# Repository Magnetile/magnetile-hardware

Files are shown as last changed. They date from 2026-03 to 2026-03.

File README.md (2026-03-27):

<div align="center">

Magnetile

# Magnetile Hardware

**Open source modular wireless macropad system**


[]()
[]()
[]()

</div>

---

Magnetile is a modular wireless input device. A central hub connects to interchangeable input tiles - mechanical keys, rotary encoders, sliders, display keys - via magnetic pogo pin connectors. The hub presents as a single BLE HID device to the host. Everything is open source.

> **Personal project by a maker in Bavaria, Germany. Not for commercial sale.**

---

## System Overview

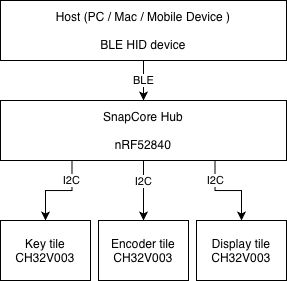
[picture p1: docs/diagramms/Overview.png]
System Overview


Tiles are hot-swappable modules. Each tile has its own small MCU communicating over I²C. The hub aggregates all input and handles the BLE stack. A single LiPo cell in the hub powers the entire system through the pogo pins.

---

## SnapCore Hub Board

The SnapCore is the first hardware in this repository — the nRF52840-based hub PCB.

### Hardware Stack

| Component | Part | Notes |
|---|---|---|
| MCU | Nordic nRF52840 (AQFN-73) | BLE 5, USB, 1MB flash, 256KB RAM |
| LDO | XC6220B331MR-G (Torex, SOT-23-5) | 3.3V, 1A, ~8µA quiescent |
| Battery charger | TP4056 | Single-cell LiPo, ~300mA charge rate |
| USB | USB-C, 5.1kΩ CC pull-downs |  |
| HF crystal | 32 MHz | nRF52840 system clock |
| RTC crystal | 32.768 kHz | Low-power RTC |
| QSPI flash | W25Q128 (16 MB) | Planned for rev 2 |
| Antenna | PCB trace (meander) | SWRA117D reference, tunable RF matching |
| Tile bus | I²C with 4.7kΩ pull-ups | Pogo pin connector |

### PCB Stackup

| Layer | Function |
|---|---|
| F.Cu | Components + signals |
| In1.Cu | Solid GND plane |
| In2.Cu | Power distribution + overflow signals |
| B.Cu | Signals |

- Copper pour excluded from antenna area

### Pinout

Magnetile

---

## Tile Architecture

Tiles are designed to be cheap and simple. The hub owns the BLE stack; tiles just report their input state over I²C when polled.

**Tile MCU target:** CH32V003 (RISC-V, I²C slave)

Each tile exposes:
- I²C slave address (configurable per tile type)
- Input state register (key states, encoder delta, slider position)
- Optional: small display framebuffer via I²C (for display tiles)

The pogo pin connector carries: `VCC`, `GND`, `SDA`, `SCL`, and an optional `INT` line for event-driven wake.

Full tile specification in [`docs/connector-pinout.md`](docs/Pinout.svg).

---

## Software

Firmware lives in the companion repository: [magnetile-firmware](https://github.com/magnetile/magnetile-firmware)

| Component | Stack |
|---|---|
| RTOS | Zephyr / Nordic NCS |
| BLE profile | HID over GATT |
| Wireless config | Web Bluetooth API (browser-based) |
| Debug | RTT (Segger J-Link / nRF9160 DK) |
| Hub–tile protocol | I²C polling, CH32V003 slave firmware |

---

## Status

| Milestone | Status |
|---|---|
| Schematic rev 1 | ✅ Complete |
| PCB layout rev 1 | ✅ Complete |
| Fab files (JLCPCB) | 🔄 In progress |
| Rev 1 bring-up | ⏳ Pending |
| Tile hardware | ⏳ Rev 2 |
| Firmware (hub) | 🔄 In progress |
| Tile firmware | ⏳ Rev 2 |
| Web config UI | ⏳ Planned |

---

## Building / Ordering

All design files are in KiCad 9. Fab outputs (Gerbers, BOM, CPL) for JLCPCB are in `snapcore/fab/`.

**Preferred suppliers:** JLCPCB (PCB + assembly), LCSC (components).

This project is designed around JLCPCB's manufacturing ecosystem. If you want to replicate the build, the Gerbers and BOM are ready to upload directly:

[**Order PCBs / PCBA from JLCPCB**](https://jlcpcb.com/?from=mnt)

For managing orders across services - PCB fabrication, assembly, 3D printing, CNC - JLCPCB offers **JLCONE**, a unified desktop platform that consolidates their full manufacturing stack (JLCPCB, JLC3DP, JLCCNC, JLCMC) into one interface. You can upload files, place orders, and track shipments across all services in one place. The desktop version includes a coupon bundle covering various services and shipping.

[**Download JLCONE**](https://jlcpcb.com/download?from=mnt)

---

## Acknowledgements

This project's prototype run is supported by **[JLCPCB](https://jlcpcb.com/?from=mnt)**. Their PCB fabrication and SMT assembly service makes iterating on dense, complex boards like the SnapCore genuinely accessible for independent open source hardware projects.

---

## License

MIT - see [`LICENSE`](LICENSE).

---

## Contributing

This is a personal project in active development. Issues and suggestions are welcome. See [`CONTRIBUTING.md`](CONTRIBUTING.md) before opening a pull request.

---

<div align="center">
<sub>Made in Bavaria · nRF52840 · KiCad · Zephyr</sub>
</div>

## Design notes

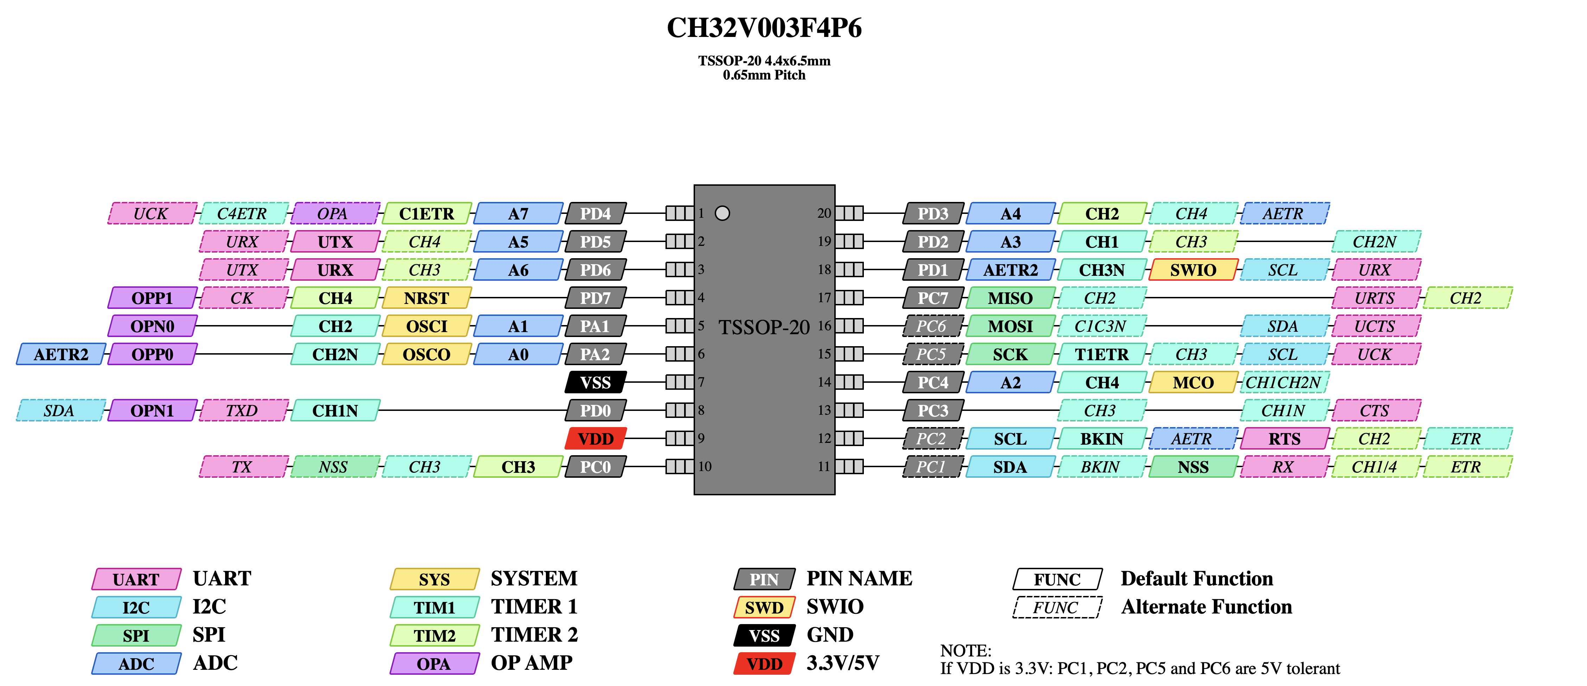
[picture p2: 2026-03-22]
Tiles/docs/CH32V003/Pinout-TSSOP-20.png

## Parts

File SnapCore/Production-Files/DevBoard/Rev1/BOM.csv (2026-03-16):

Comment | Designator | Footprint | LCSC | Quantity
0.5pF | C16 | C_0402_1005Metric | C1544 | 1
0.8pF | C15 | C_0402_1005Metric | C40459 | 1
0R | R7 | R_0603_1608Metric | C95177 | 1
100K | R6 | R_0402_1005Metric | C25741 | 1
100NF | C7 | C_0805_2012Metric | C49678 | 1
100nF | C18 | C_0603_1608Metric | C14663 | 1
100nF | C8 | C_0402_1005Metric | C1525 | 1
100pF | C19 | C_0402_1005Metric | C1546 | 1
10k | R18 | R_0402_1005Metric | C25744 | 1
10uF | C2,C24 | C_0402_1005Metric | C15525 | 2
10uH | L2 | L_0402_1005Metric | C48946156 | 1
12pF | C10,C20,C21,C9 | C_0402_1005Metric | C1547 | 4
1M_1% | R22 | R_0603_1608Metric | C22935 | 1
1k | R3,R4 | R_0603_1608Metric | C21190 | 2
1nF | C17 | C_0402_1005Metric | C1523 | 1
2.2k | R9 | R_0402_1005Metric | C25879 | 1
2.2uF | C1,C13,C22,C3 | C_0402_1005Metric | C12530 | 4
2.2uF | C11,C12 | C_0603_1608Metric | C23630 | 2
2.2uF | C23 | C_0805_2012Metric | C377773 | 1
32.768KHz | Y1 | Crystal_SMD_2016-4Pin_2.0x1.6mm | C437148 | 1
32MHz | Y2 | Crystal_SMD_2016-4Pin_2.0x1.6mm | C187794 | 1
33R | R19,R20 | R_0402_1005Metric | C25105 | 2
4.7k | R16,R17 | R_0402_1005Metric | C25900 | 2
4.7nH | L1 | L_0402_1005Metric | C13595 | 1
4k | R5 | R_0603_1608Metric | C22940 | 1
5.1k | R1,R2 | R_0402_1005Metric | C25905 | 2
500mA | F2 | Fuse_1206_3216Metric | C20798 | 1
510k_1% | R23 | R_0603_1608Metric | C23192 | 1
820pF | C14 | C_0402_1005Metric | C1523 | 1
AO3407A | Q1 | SOT-23 | C15155 | 1
CHG0 | RED1 | LED_0603_1608Metric | C2286 | 1
Green | D2 | LED_0805_2012Metric | C2297 | 1
Red | D1 | LED_0805_2012Metric | C84256 | 1
SDM20U40-7, 40V;250mA | D5 | D_SOD-523 | C139439 | 1
TP4056-42-ESOP8 | U5 | SOIC-8-1EP_3.9x4.9mm_P1.27mm_EP2.41x3.3mm_ThermalVias | C16581 | 1
TS-1187A | SW2 | SW_Push_1P1T_XKB_TS-1187A | C318884 | 1
USB_C_Receptacle_USB2.0_16P | J2 | USB_C_Receptacle_GCT_USB4105-xx-A_16P_TopMnt_Horizontal | C136423 | 1
XC6220B331MR | U2 | SOT-23-5 | C3040644 | 1
nRF52840-QIXX | U1 | Nordic_AQFN-73-1EP_7x7mm_P0.5mm | C190794 | 1
SWRA117D_2.4Ghz | AE1 | Texas_SWRA117D_2.4GHz_Right |  | 1
Conn_01x18_Pin | J3 | PinHeader_1x18_P1.27mm_Vertical |  | 1

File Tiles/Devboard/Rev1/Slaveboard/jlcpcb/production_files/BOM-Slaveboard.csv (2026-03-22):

Comment | Designator | Footprint | LCSC | Quantity
100nF | C1,C2 | C_0603_1608Metric | C14663 | 2
1N4148W | D1,D10,D11,D12,D13,D14,D15,D16,D2,D3,D4,D5,D6,D7,D8,D9 | D_SOD-123 | C81598 | 16
CH32V003FxPx | U1 | TSSOP-20_4.4x6.5mm_P0.65mm | C5187096 | 1
TS-1178A | RESET | SW_Push_1P1T_XKB_TS-1187A | C318884 | 1

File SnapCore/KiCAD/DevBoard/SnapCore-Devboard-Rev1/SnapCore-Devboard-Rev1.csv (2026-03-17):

Reference | Qty | Value | DNP | Exclude from BOM | Exclude from Board | Footprint | Datasheet
AE1 | 1 | P/N 2450AT18A100E-AEC |  |  |  | RF_Antenna:Johanson_2450AT18x100 | ~
BAT_CONN2 | 1 | Battery JST 3.7V |  |  |  | Connector_JST:JST_EH_B2B-EH-A_1x02_P2.50mm_Vertical | ~
C1,C3,C11,C12,C13,C22,C23 | 7 | 2.2uF |  |  |  | Capacitor_SMD:C_0805_2012Metric | ~
C2 | 1 | 10uF |  |  |  | Capacitor_SMD:C_0603_1608Metric | ~
C7 | 1 | 100NF |  |  |  | Capacitor_SMD:C_0805_2012Metric | ~
C8,C18 | 2 | 100nF |  |  |  | Capacitor_SMD:C_0805_2012Metric | ~
C9,C10 | 2 | 10pF |  |  |  | Capacitor_SMD:C_0805_2012Metric | ~
C14 | 1 | 820pF |  |  |  | Capacitor_SMD:C_0805_2012Metric | ~
C15 | 1 | 0.8pF |  |  |  | Capacitor_SMD:C_0805_2012Metric | ~
C16 | 1 | 0.5pF |  |  |  | Capacitor_SMD:C_0805_2012Metric | ~
C17 | 1 | 1nF |  |  |  | Capacitor_SMD:C_0805_2012Metric | ~
C19 | 1 | 100pF |  |  |  | Capacitor_SMD:C_0805_2012Metric | ~
C20,C21 | 2 | 15pF |  |  |  | Capacitor_SMD:C_0805_2012Metric | ~
C24 | 1 | 10uF |  |  |  | Capacitor_SMD:C_0805_2012Metric | ~
D1 | 1 | Red |  |  |  | LED_SMD:LED_0201_0603Metric | ~
D2 | 1 | Green |  |  |  | LED_SMD:LED_0201_0603Metric | ~
D5 | 1 | SDM20U40-7, 40V;250mA |  |  |  | Diode_SMD:D_SOD-523 | ~
F2 | 1 | 500mA |  |  |  | Fuse:Fuse_1206_3216Metric | ~
J2 | 1 | USB_C_Receptacle_USB2.0_16P |  |  |  | Connector_USB:USB_C_Receptacle_GCT_USB4105-xx-A_16P_TopMnt_Horizontal | https://www.usb.org/sites/default/files/documents/usb_type-c.zip
J_3V3 | 1 | 3V3 |  |  |  | Connector_PinHeader_1.00mm:PinHeader_1x01_P1.00mm_Vertical | ~
J_AIN1 | 1 | AIN1 |  |  |  | Connector_PinHeader_1.00mm:PinHeader_1x01_P1.00mm_Vertical | ~
J_GND1,J_GND2 | 2 | GND |  |  |  | Connector_PinHeader_1.00mm:PinHeader_1x01_P1.00mm_Vertical | ~
J_I2C_SCL1 | 1 | I2C_SCL |  |  |  | Connector_PinHeader_1.00mm:PinHeader_1x01_P1.00mm_Vertical | ~
J_I2C_SDA1 | 1 | I2C_SDA |  |  |  | Connector_PinHeader_1.00mm:PinHeader_1x01_P1.00mm_Vertical | ~
J_NFC1 | 1 | NFC1 |  |  |  | Connector_PinHeader_1.00mm:PinHeader_1x01_P1.00mm_Vertical | ~
J_NFC2 | 1 | NFC2 |  |  |  | Connector_PinHeader_1.00mm:PinHeader_1x01_P1.00mm_Vertical | ~
J_PDM_CLK1 | 1 | PDM_CLK |  |  |  | Connector_PinHeader_1.00mm:PinHeader_1x01_P1.00mm_Vertical | ~
J_PDM_DATA1 | 1 | PDM_DATA |  |  |  | Connector_PinHeader_1.00mm:PinHeader_1x01_P1.00mm_Vertical | ~
J_SWDCLK1 | 1 | SWDCLK |  |  |  | Connector_PinHeader_1.00mm:PinHeader_1x01_P1.00mm_Vertical | ~
J_SWDIO1 | 1 | SWDIO |  |  |  | Connector_PinHeader_1.00mm:PinHeader_1x01_P1.00mm_Vertical | ~
J_VBUS1 | 1 | VBUS |  |  |  | Connector_PinHeader_1.00mm:PinHeader_1x01_P1.00mm_Vertical | ~
L1 | 1 | 4.7nH |  |  |  | Inductor_SMD:L_0402_1005Metric | ~
L2 | 1 | 10uH |  |  |  | Inductor_SMD:L_0402_1005Metric | ~
Q1 | 1 | LP0404N3T5G |  |  |  | Package_TO_SOT_SMD:SOT-883 | ~
R1,R2 | 2 | 5.1k |  |  |  | Resistor_SMD:R_0402_1005Metric | ~
R3,R4 | 2 | 1k |  |  |  | Resistor_SMD:R_0603_1608Metric | ~
R5 | 1 | 4k |  |  |  | Resistor_SMD:R_0603_1608Metric | ~
R6 | 1 | 100K |  |  |  | Resistor_SMD:R_0402_1005Metric | ~
R9 | 1 | 2.2k |  |  |  | Resistor_SMD:R_0201_0603Metric | ~
R16,R17 | 2 | 4.7k |  |  |  | Resistor_SMD:R_0402_1005Metric | ~
R18 | 1 | 10k |  |  |  | Resistor_SMD:R_0201_0603Metric | ~
R19,R20 | 2 | 33R |  |  |  | Resistor_SMD:R_0201_0603Metric | ~
R22 | 1 | 1M_1% |  |  |  | Resistor_SMD:R_0402_1005Metric | ~
R23 | 1 | 510k_1% |  |  |  | Resistor_SMD:R_0402_1005Metric | ~
RED1 | 1 | CHG0 |  |  |  | LED_SMD:LED_0201_0603Metric | ~
SW2 | 1 | RESET PTS125 |  |  |  | Button_Switch_SMD:SW_Push_1P1T_NO_CK_KSC9xxJ | ~
U1 | 1 | nRF52840-QIXX |  |  |  | Package_DFN_QFN:Nordic_AQFN-73-1EP_7x7mm_P0.5mm | https://docs-be.nordicsemi.com/bundle/ps_nrf52840/attach/nRF52840_PS_v1.11.pdf?_LANG=enus
U2 | 1 | XC6220B331MR |  |  |  | Package_TO_SOT_SMD:SOT-23-5 | https://www.torexsemi.com/file/xc6220/XC6220.pdf
U5 | 1 | TP4056-42-ESOP8 |  |  |  | Package_SO:SOIC-8-1EP_3.9x4.9mm_P1.27mm_EP2.41x3.3mm_ThermalVias | https://www.lcsc.com/datasheet/lcsc_datasheet_2410121619_TOPPOWER-Nanjing-Extension-Microelectronics-TP4056-42-ESOP8_C16581.pdf
Y1 | 1 | 32.768KHz |  |  |  | Crystal:Crystal_SMD_2016-4Pin_2.0x1.6mm | ~
Y2 | 1 | 32MHz |  |  |  | Crystal:Crystal_SMD_2016-4Pin_2.0x1.6mm | ~

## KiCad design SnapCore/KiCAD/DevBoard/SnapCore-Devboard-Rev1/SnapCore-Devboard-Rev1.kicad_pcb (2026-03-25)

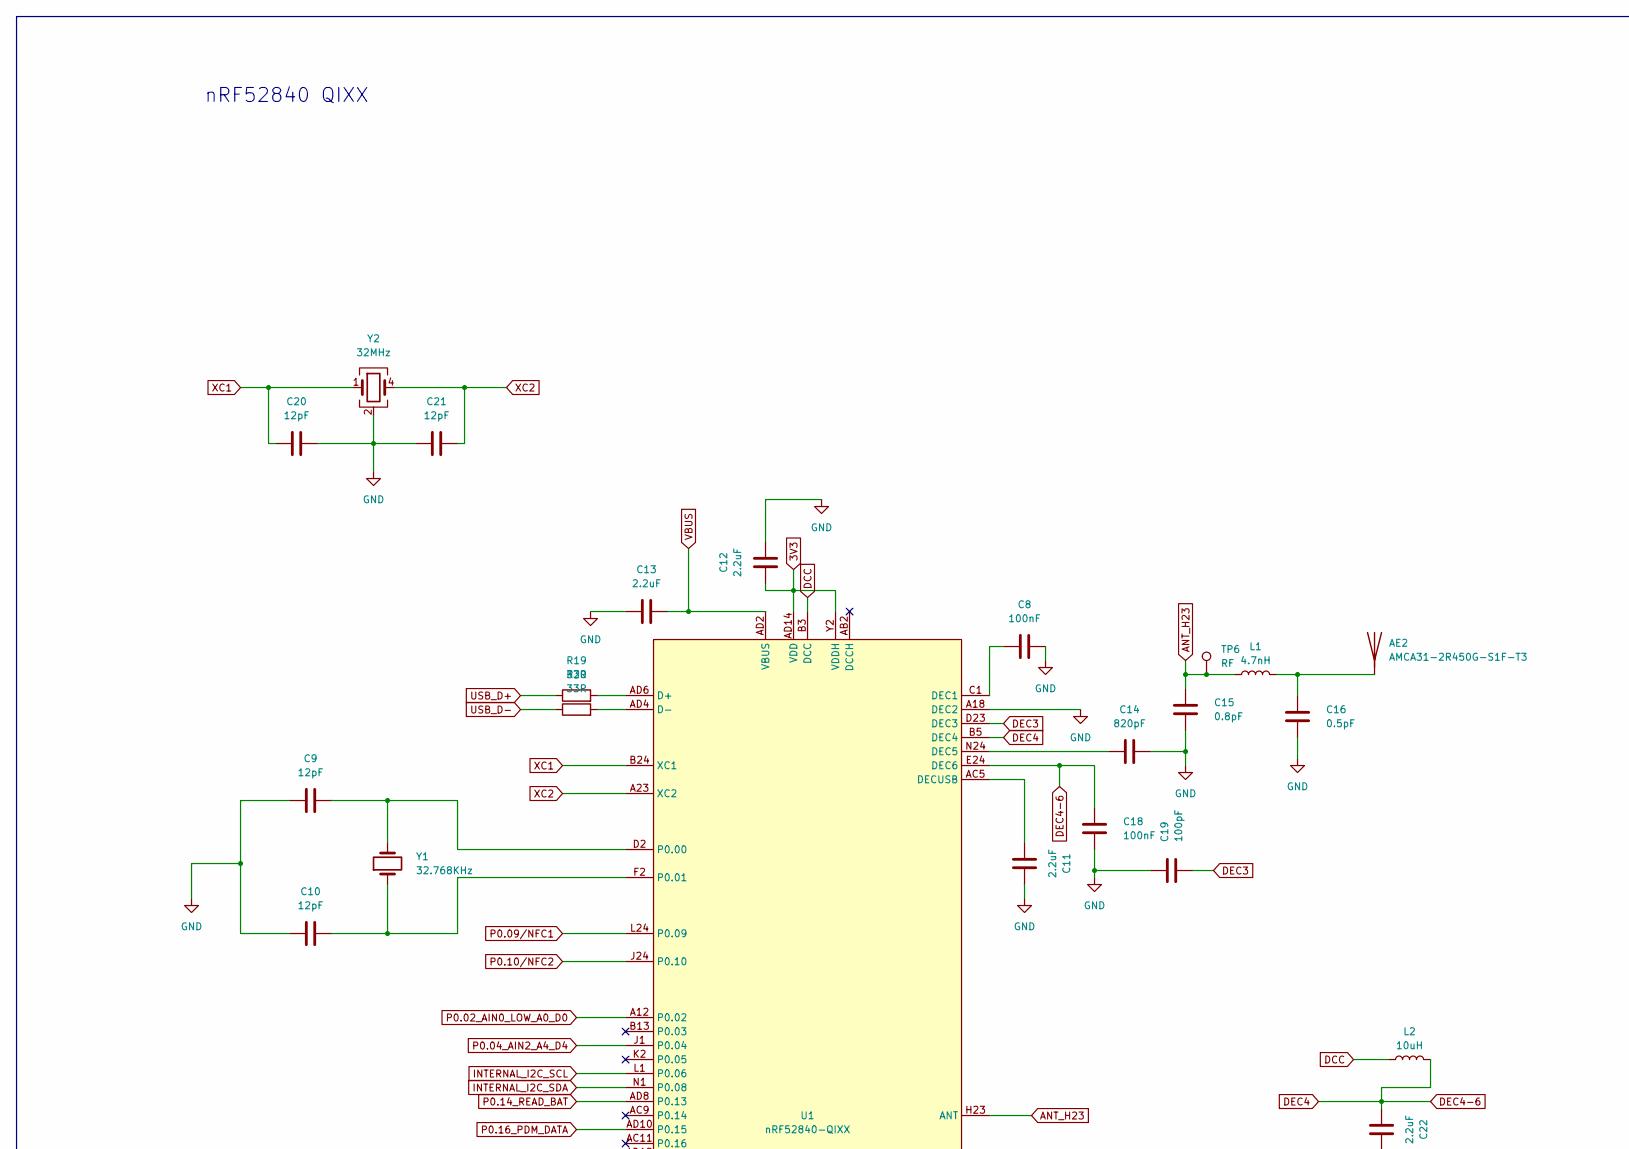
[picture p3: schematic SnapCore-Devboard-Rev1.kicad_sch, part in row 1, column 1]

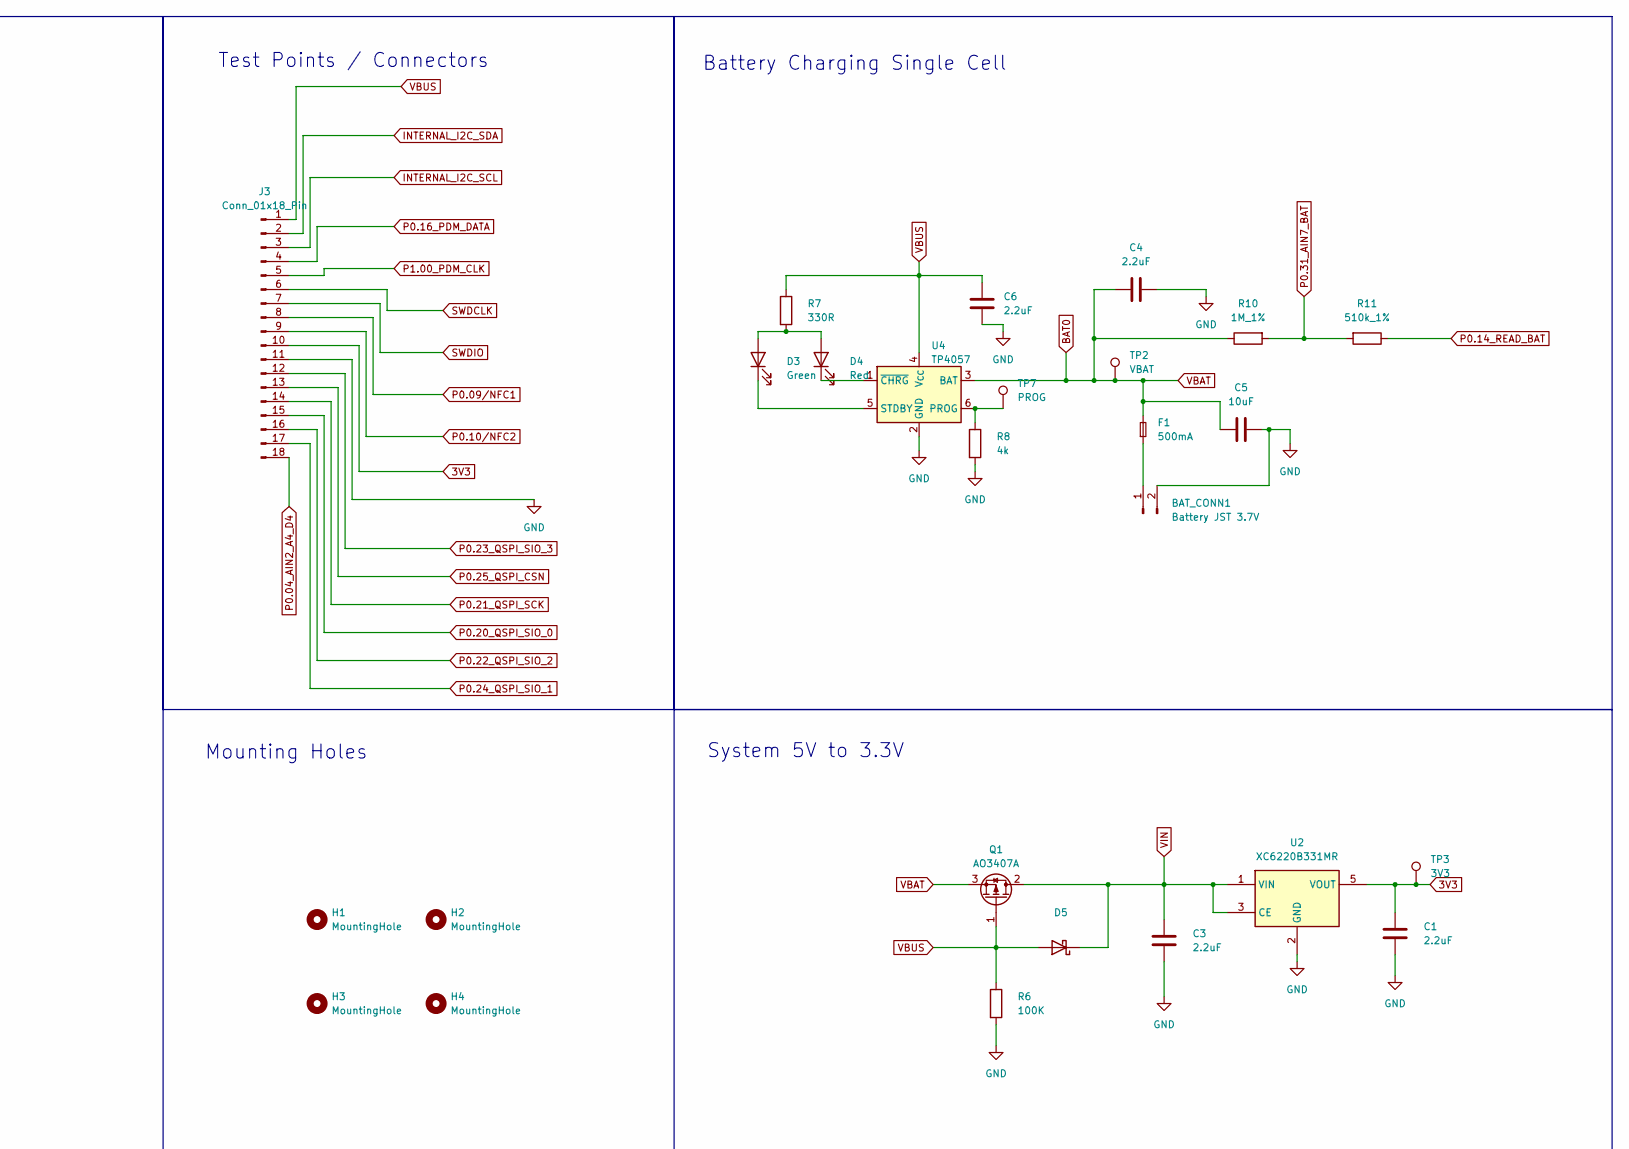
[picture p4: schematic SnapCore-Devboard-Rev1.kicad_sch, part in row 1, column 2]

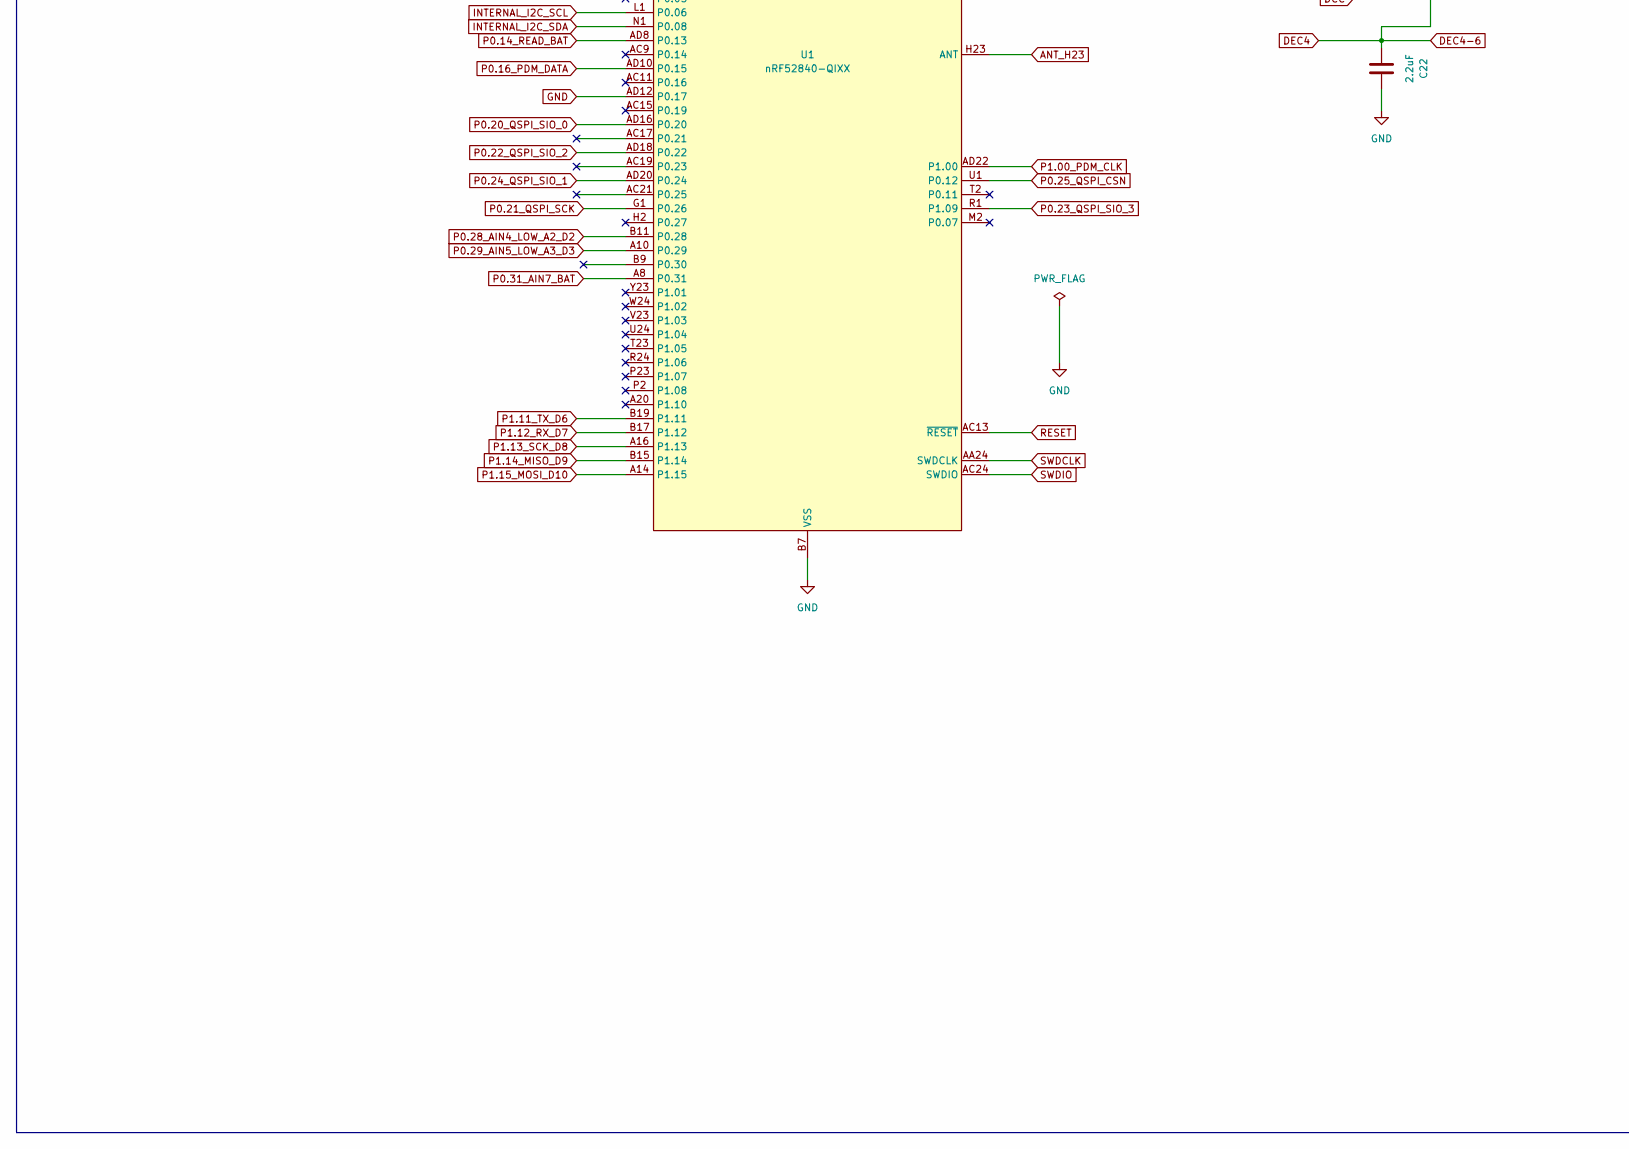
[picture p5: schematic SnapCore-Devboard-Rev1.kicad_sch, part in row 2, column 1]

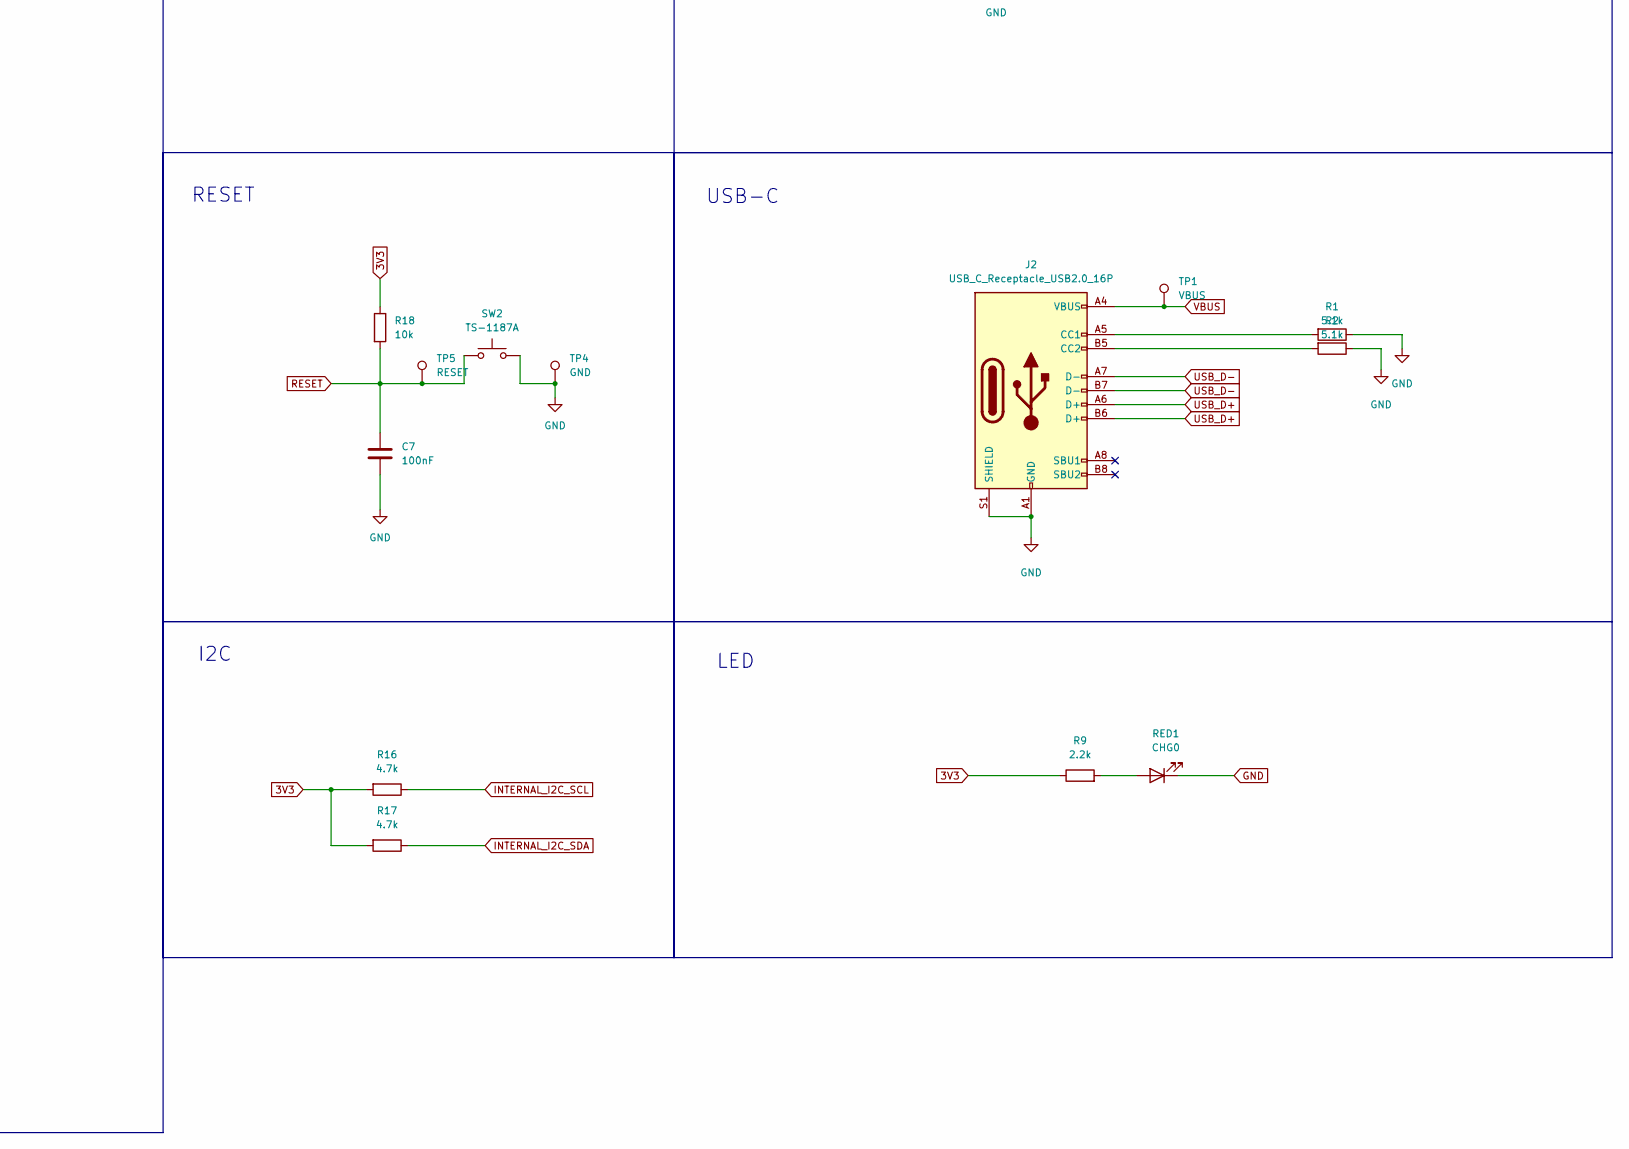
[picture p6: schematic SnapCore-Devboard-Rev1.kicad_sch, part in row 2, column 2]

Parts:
AE2: AMCA31-2R450G-S1F-T3; XDCR_AMCA31-2R450G-S1F-T3
BAT_CONN1: Battery JST 3.7V; JST_EH_B2B-EH-A_1x02_P2.50mm_Vertical
C1, C3, C13, C22: 2.2uF; C_0402_1005Metric
C4: 2.2uF; C_0805_2012Metric
C5: 10uF; C_0402_1005Metric
C6, C11, C12: 2.2uF; C_0603_1608Metric
C7: 100nF; C_0805_2012Metric
C8: 100nF; C_0402_1005Metric
C9, C10, C20, C21: 12pF; C_0402_1005Metric
C14: 820pF; C_0402_1005Metric
C15: 0.8pF; C_0402_1005Metric
C16: 0.5pF; C_0402_1005Metric
C18: 100nF; C_0603_1608Metric
C19: 100pF; C_0402_1005Metric
D3: Green; LED_0805_2012Metric
D4: Red; LED_0805_2012Metric
D5: SDM20U40-7, 40V;250mA; D_SOD-523
F1: 500mA; Fuse_1206_3216Metric
H1, H2, H3, H4: MountingHole; MountingHole_2.2mm_M2_ISO7380_Pad
J2: USB_C_Receptacle_USB2.0_16P; USB_C_Receptacle_GCT_USB4105-xx-A_16P_TopMnt_Horizontal
J3: Conn_01x18_Pin; PinHeader_1x18_P1.27mm_Vertical
L1: 4.7nH; L_0402_1005Metric
L2: 10uH; L_0402_1005Metric
Q1: AO3407A; SOT-23
R1, R2: 5.1k; R_0402_1005Metric
R6: 100K; R_0402_1005Metric
R7: 330R; R_0603_1608Metric
R8: 4k; R_0603_1608Metric
R9: 2.2k; R_0402_1005Metric
R10: 1M_1%; R_0603_1608Metric
R11: 510k_1%; R_0603_1608Metric
R16, R17: 4.7k; R_0402_1005Metric
R18: 10k; R_0402_1005Metric
R19, R20: 33R; R_0402_1005Metric
RED1: CHG0; LED_0603_1608Metric
SW2: TS-1187A; SW_Push_1P1T_XKB_TS-1187A
TP1: VBUS; TestPoint_Pad_D2.0mm
TP2: VBAT; TestPoint_Pad_D2.0mm
TP3: 3V3; TestPoint_Pad_D2.0mm
TP4: GND; TestPoint_Pad_D2.0mm
TP5: RESET; TestPoint_Pad_D2.0mm
TP6: RF; TestPoint_Pad_D2.0mm
TP7: PROG; TestPoint_Pad_D2.0mm
U1: nRF52840-QIXX; Nordic_AQFN-73-1EP_7x7mm_P0.5mm
U2: XC6220B331MR; SOT-23-5
U4: TP4057; TSOT-23-6
Y1: 32.768KHz; Crystal_SMD_3215-2Pin_3.2x1.5mm
Y2: 32MHz; Crystal_SMD_2016-4Pin_2.0x1.6mm

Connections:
3V3: C1.1, C12.2, J3.10, R9.1, R16.2, R17.2, R18.1, TP3.1, U1.A22 (VDD), U1.AD14 (VDD), U1.AD23 (VDD), U1.B1 (VDD), U1.W1 (VDD), U1.Y2 (VDDH), U2.5 (VOUT)
ANT_H23: C15.1, L1.1, TP6.1, U1.H23 (ANT)
BAT0: C4.1, C5.1, F1.2, Q1.3 (S), R10.1, TP2.1, U4.3 (BAT)
DCC: L2.1, U1.B3 (DCC)
DEC3: C19.2, U1.D23 (DEC3)
DEC4: C18.1, C22.2, L2.2, U1.B5 (DEC4), U1.E24 (DEC6)
GND: BAT_CONN1.2, C1.2, C3.2, C4.2, C5.2, C6.1, C7.1, C8.1, C9.2, C10.2, C11.1, C12.1, C13.1, C14.1, C15.2, C16.2, C18.2, C19.1, C20.1, C21.1, C22.1, J2.A1 (GND), J2.A12 (GND), J2.B1 (GND), J2.B12 (GND), J2.S1 (SHIELD), J3.11, R1.1, R2.1, R6.2, R8.2, RED1.1 (K), SW2.2, TP4.1, U1.A18 (DEC2), U1.AD12 (P0.17), U1.B7 (VSS), U1.EP (VSS), U1.F23 (VSS_PA), U2.2 (GND), U4.2 (GND), Y2.2 (G), Y2.3 (G); also elsewhere on the board
INTERNAL_I2C_SCL: J3.3, R16.1, U1.L1 (P0.06)
INTERNAL_I2C_SDA: J3.2, R17.1, U1.N1 (P0.08)
unnamed: AE2.1 (A), C16.1, L1.2
unnamed 10: BAT_CONN1.1, F1.1; also elsewhere on the board
unnamed: D3.2 (A), D4.2 (A), R7.2
unnamed: D3.1 (K), U4.5 (STDBY)
unnamed: D4.1 (K), U4.1 (~CHRG)
unnamed: J2.A5 (CC1), R1.2
unnamed: J2.B5 (CC2), R2.2
unnamed: R9.2, RED1.2 (A)
unnamed: R19.2, U1.AD6 (D+)
unnamed: R20.2, U1.AD4 (D-)
unnamed: C8.2, U1.C1 (DEC1)
unnamed: C14.2, U1.N24 (DEC5)
unnamed: C11.2, U1.AC5 (DECUSB)
unnamed: C9.1, U1.D2 (P0.00), Y1.2
unnamed: C10.1, U1.F2 (P0.01), Y1.1
unnamed: R8.1, TP7.1, U4.6 (PROG)
P0.02_AIN0_LOW_A0_D0: U1.A12 (P0.02)
P0.04_AIN2_A4_D4: J3.18, U1.J1 (P0.04)
P0.09/NFC1: J3.8, U1.L24 (P0.09)
P0.10/NFC2: J3.9, U1.J24 (P0.10)
P0.14_READ_BAT: R11.1, U1.AD8 (P0.13)
P0.16_PDM_DATA: J3.4, U1.AD10 (P0.15)
P0.20_QSPI_SIO_0: J3.15, U1.AD16 (P0.20)
P0.21_QSPI_SCK: J3.14, U1.G1 (P0.26)
P0.22_QSPI_SIO_2: J3.16, U1.AD18 (P0.22)
P0.23_QSPI_SIO_3: J3.12, U1.R1 (P1.09)
P0.24_QSPI_SIO_1: J3.17, U1.AD20 (P0.24)
P0.25_QSPI_CSN: J3.13, U1.U1 (P0.12)
P0.28_AIN4_LOW_A2_D2: U1.B11 (P0.28)
P0.29_AIN5_LOW_A3_D3: U1.A10 (P0.29)
P0.31_AIN7_BAT: R10.2, R11.2, U1.A8 (P0.31)
P1.00_PDM_CLK: J3.5, U1.AD22 (P1.00)
P1.11_TX_D6: U1.B19 (P1.11)
P1.12_RX_D7: U1.B17 (P1.12)
P1.13_SCK_D8: U1.A16 (P1.13)
P1.14_MISO_D9: U1.B15 (P1.14)
P1.15_MOSI_D10: U1.A14 (P1.15)
RESET: C7.2, R18.2, SW2.1, TP5.1, U1.AC13 (~RESET)
SWDCLK: J3.6, U1.AA24 (SWDCLK)
SWDIO: J3.7, U1.AC24 (SWDIO)
USB_D+: J2.A6 (D+), J2.B6 (D+), R19.1
USB_D-: J2.A7 (D-), J2.B7 (D-), R20.1
VBUS: C6.2, C13.2, D5.2 (A), J2.A4 (VBUS), J2.A9 (VBUS), J2.B4 (VBUS), J2.B9 (VBUS), J3.1, Q1.1 (G), R6.1, R7.1, TP1.1, U1.AD2 (VBUS), U4.4 (V_{CC})
VIN: C3.1, D5.1 (K), Q1.2 (D), U2.1 (VIN), U2.3 (CE)
XC1: C20.2, U1.B24 (XC1), Y2.1
XC2: C21.2, U1.A23 (XC2), Y2.4

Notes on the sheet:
USB-C
Test Points / Connectors
LED
Mounting Holes
RESET
I2C
Battery Charging Single Cell
System 5V to 3.3V
nRF52840 QIXX

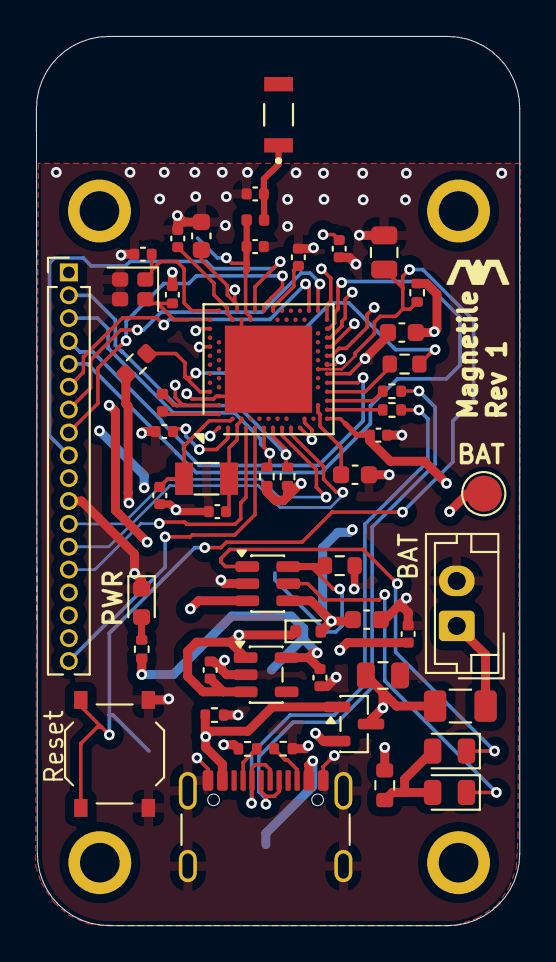
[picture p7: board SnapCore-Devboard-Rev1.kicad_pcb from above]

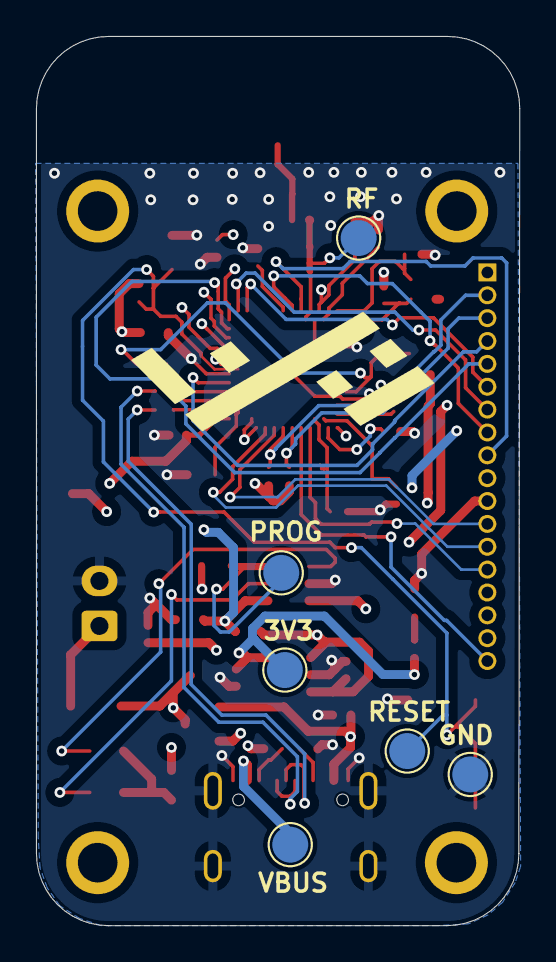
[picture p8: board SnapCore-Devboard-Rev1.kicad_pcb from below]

Board: 4 copper layers, 26.8 x 49.4 mm, 62 parts (6 on the bottom side), 47 nets.

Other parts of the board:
BAT: Battery JST 3.7V; JST_EH_B2B-EH-A_1x02_P2.50mm_Vertical

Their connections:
GND: BAT.2; also elsewhere on the board
unnamed 10: BAT.1; also elsewhere on the board

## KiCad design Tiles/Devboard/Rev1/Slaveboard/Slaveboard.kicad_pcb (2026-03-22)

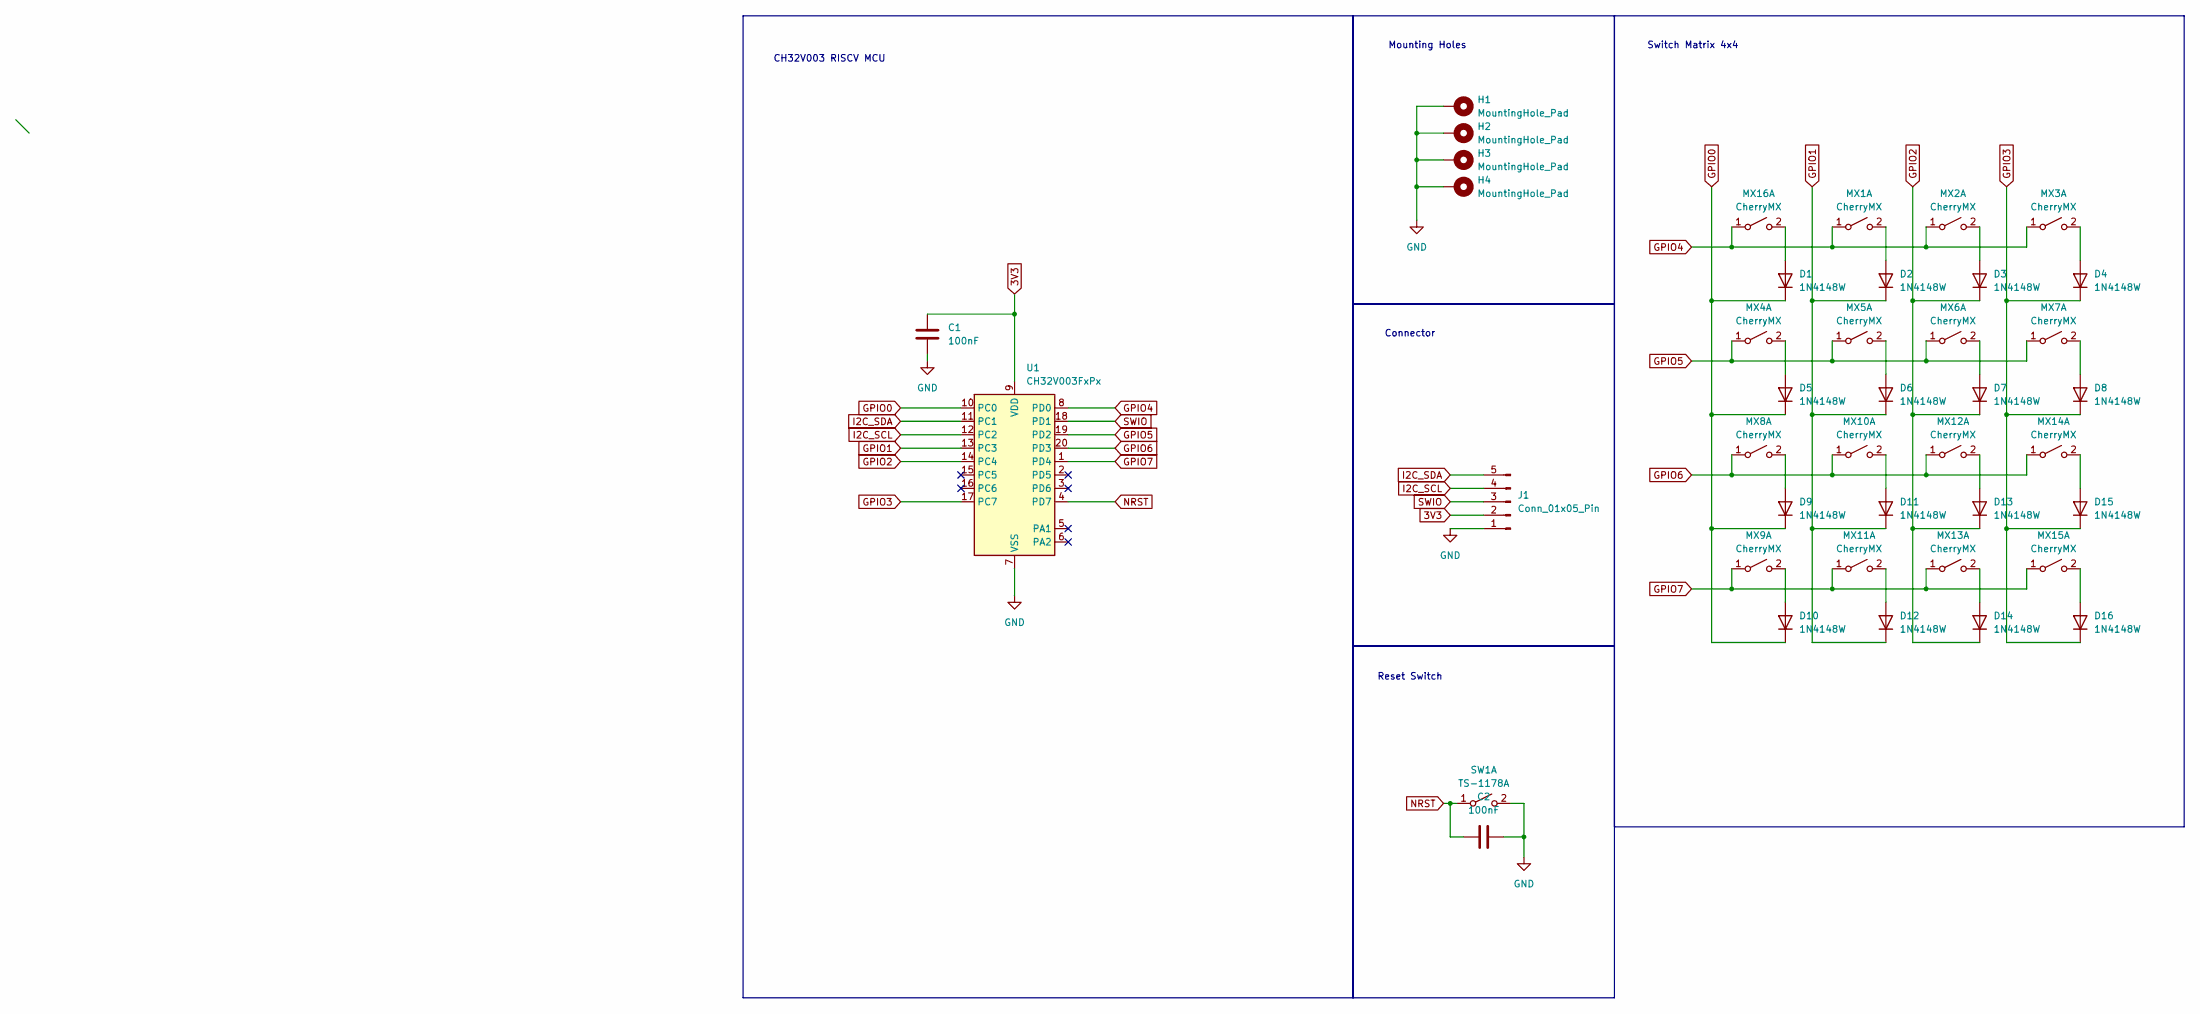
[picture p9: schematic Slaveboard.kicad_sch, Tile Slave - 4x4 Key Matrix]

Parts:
C1, C2: 100nF; C_0603_1608Metric
D1, D2, D3, D4, D5, D6, D7, D8, D9, D10, D11, D12, D13, D14, D15, D16: 1N4148W; D_SOD-123
H1, H2, H3, H4: MountingHole_Pad; MountingHole_2.2mm_M2_DIN965_Pad
J1: Conn_01x05_Pin; PinHeader_1x05_P1.27mm_Vertical
MX1, MX2, MX3, MX4, MX5, MX6, MX7, MX8, MX9, MX10, MX11, MX12, MX13, MX14, MX15, MX16: CherryMX; SW_Cherry_MX_1.00u_PCB
SW1: TS-1178A; SW_Push_1P1T_XKB_TS-1187A
U1: CH32V003FxPx; TSSOP-20_4.4x6.5mm_P0.65mm

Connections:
3V3: C1.1, J1.2, U1.9 (VDD)
GND: C1.2, C2.2, H1.1, H2.1, H3.1, H4.1, J1.1, SW1.2 (B), U1.7 (VSS); also elsewhere on the board
GPIO0: D1.1 (K), D5.1 (K), D9.1 (K), D10.1 (K), U1.10 (PC0)
GPIO1: D2.1 (K), D6.1 (K), D11.1 (K), D12.1 (K), U1.13 (PC3)
GPIO2: D3.1 (K), D7.1 (K), D13.1 (K), D14.1 (K), U1.14 (PC4)
GPIO3: D4.1 (K), D8.1 (K), D15.1 (K), D16.1 (K), U1.17 (PC7)
GPIO4: MX1.1 (A), MX2.1 (A), MX3.1 (A), MX16.1 (A), U1.8 (PD0)
GPIO5: MX4.1 (A), MX5.1 (A), MX6.1 (A), MX7.1 (A), U1.19 (PD2)
GPIO6: MX8.1 (A), MX10.1 (A), MX12.1 (A), MX14.1 (A), U1.20 (PD3)
GPIO7: MX9.1 (A), MX11.1 (A), MX13.1 (A), MX15.1 (A), U1.1 (PD4)
I2C_SCL: J1.4, U1.12 (PC2)
I2C_SDA: J1.5, U1.11 (PC1)
NRST: C2.1, SW1.1 (A), U1.4 (PD7); also elsewhere on the board
unnamed: D1.2 (A), MX16.2 (B)
unnamed: D2.2 (A), MX1.2 (B)
unnamed: D3.2 (A), MX2.2 (B)
unnamed: D4.2 (A), MX3.2 (B)
unnamed: D5.2 (A), MX4.2 (B)
unnamed: D6.2 (A), MX5.2 (B)
unnamed: D7.2 (A), MX6.2 (B)
unnamed: D8.2 (A), MX7.2 (B)
unnamed: D9.2 (A), MX8.2 (B)
unnamed: D10.2 (A), MX9.2 (B)
unnamed: D11.2 (A), MX10.2 (B)
unnamed: D12.2 (A), MX11.2 (B)
unnamed: D13.2 (A), MX12.2 (B)
unnamed: D14.2 (A), MX13.2 (B)
unnamed: D15.2 (A), MX14.2 (B)
unnamed: D16.2 (A), MX15.2 (B)
SWIO: J1.3, U1.18 (PD1)

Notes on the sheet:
Reset Switch
CH32V003 RISCV MCU
Mounting Holes
Connector
Switch Matrix 4x4

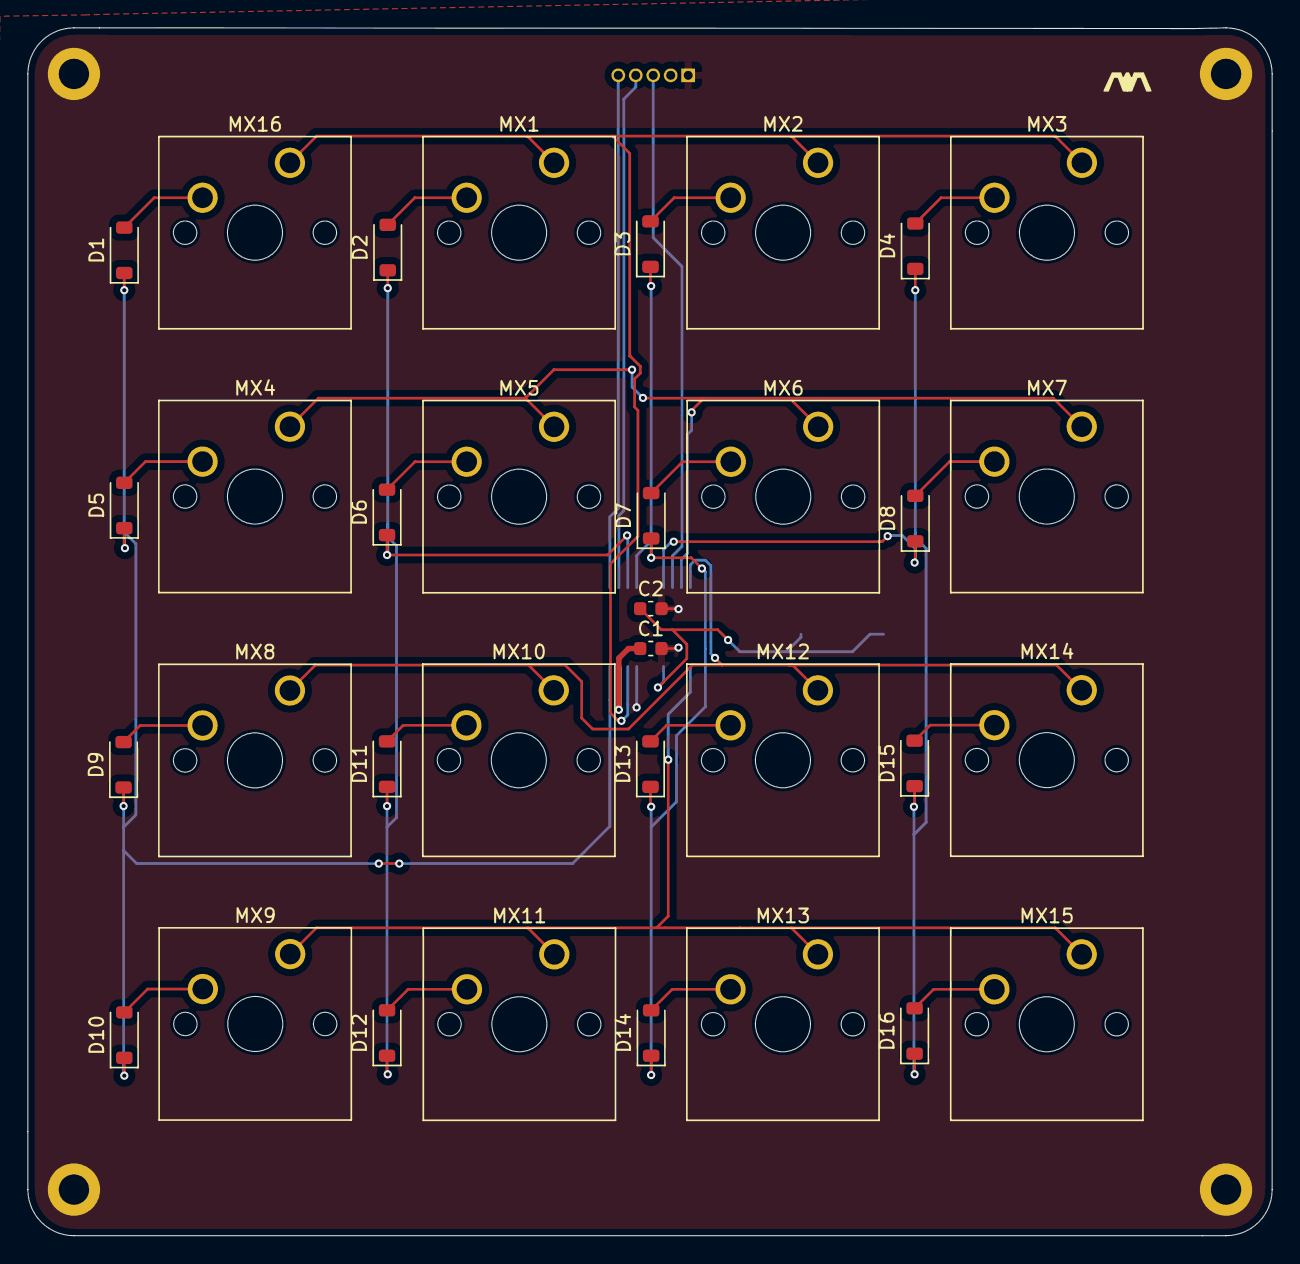
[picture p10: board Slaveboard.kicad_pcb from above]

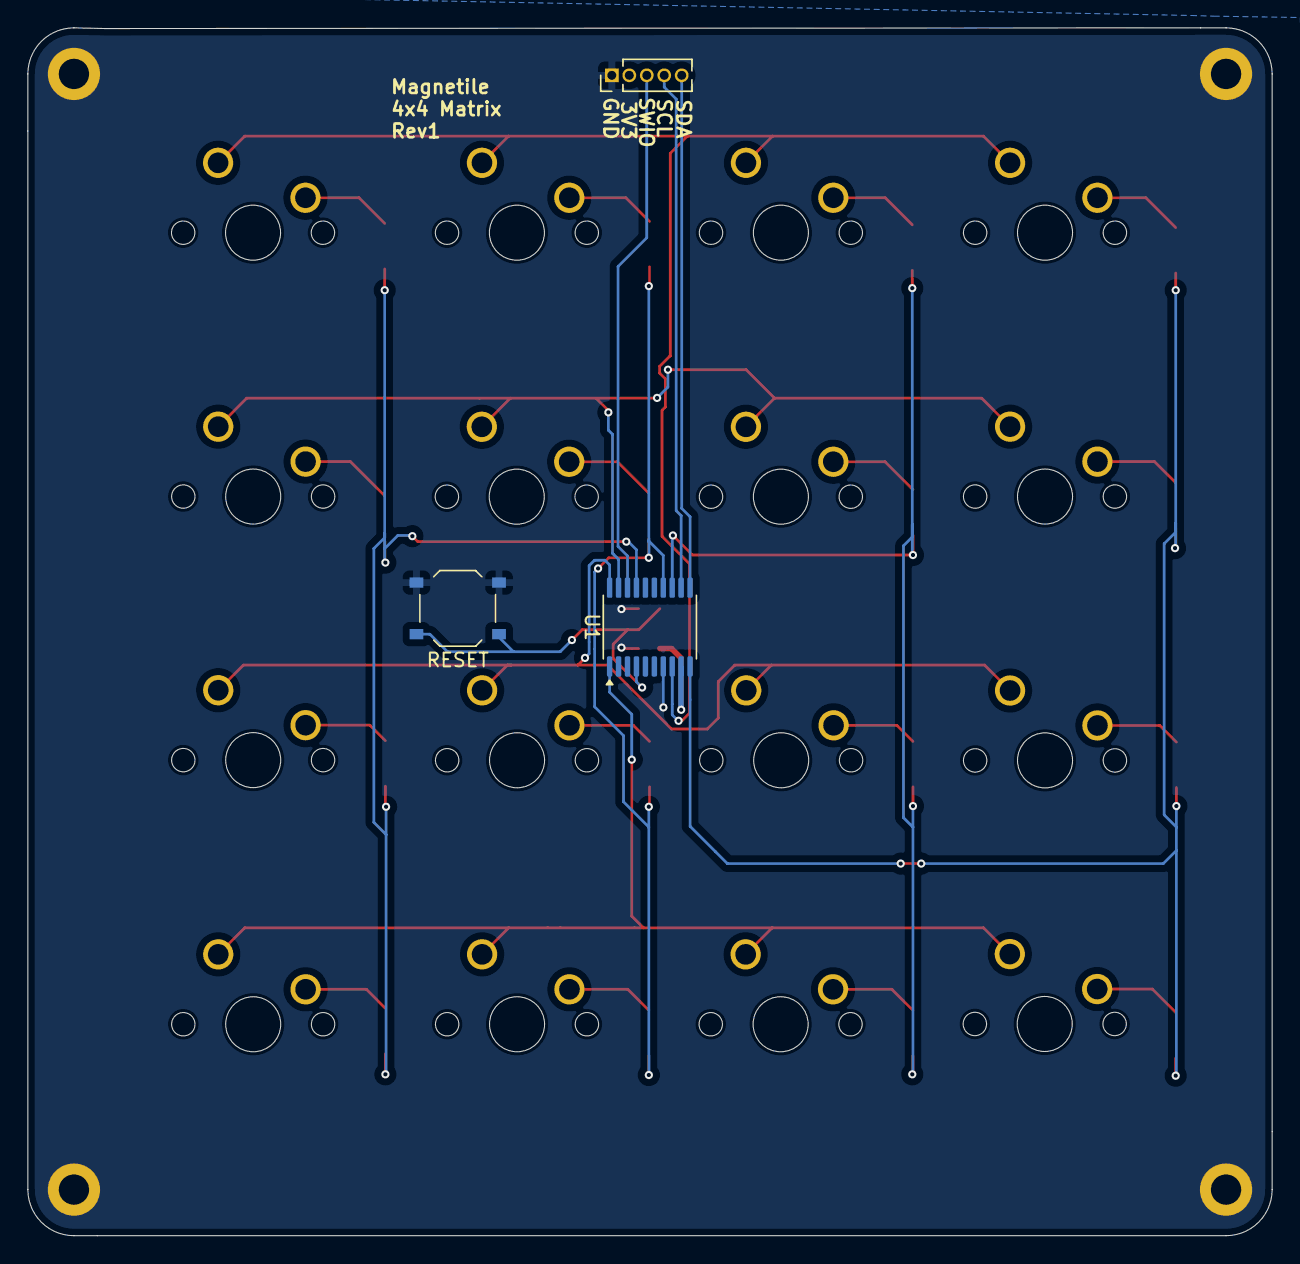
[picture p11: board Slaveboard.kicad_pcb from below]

Board: 4 copper layers, 90.5 x 87.8 mm, 41 parts (3 on the bottom side), 30 nets.

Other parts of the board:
RESET: TS-1178A; SW_Push_1P1T_XKB_TS-1187A

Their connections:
GND: RESET.2 (B); also elsewhere on the board
NRST: RESET.1 (A); also elsewhere on the board

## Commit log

2026-03-16 Added SnapCore Rev1 Devboard files
    [BOM.csv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]
2026-03-16 Added KiCad Files
2026-03-16 KiCAD Files Update
2026-03-16 Final added Kicad Files
    [SnapCore-Devboard-Rev1.csv, SnapCore-Devboard-Rev1.kicad_pcb, SnapCore-Devboard-Rev1.kicad_sch]
2026-03-20 Added first revision of a tile devboard
    Based on CH32V003F4P6 MCU
    [BOM-Slaveboard.csv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]
2026-03-20 Added Silkscreen QoL
    [Slaveboard.kicad_pcb]
2026-03-20 Updated Production files
    [BOM-Slaveboard.csv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]
2026-03-22 Smaller Update
    [Slaveboard.kicad_sch]
2026-03-22 Updated Devboard to use Chip Antenna instead of PCB Antenna for easier RF matching
    [BOM-SnapCore-Devboard-Rev1.csv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]
2026-03-22 Removed unecessary silkscreen, Fixed small layout issue
    [CPL-SnapCore-Devboard-Rev1.csv, SnapCore-Devboard-Rev1-CuBottom.gbr, SnapCore-Devboard-Rev1-CuIn1.gbr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]
2026-03-25 Switched to TP4057 Charger IC, Added J4 to bottom pinout
    [BOM-SnapCore-Devboard-Rev1.csv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]
2026-03-25 Fixed trace for pwr led being too small
    [SnapCore-Devboard-Rev1-CuBottom.gbr, SnapCore-Devboard-Rev1-CuIn1.gbr, SnapCore-Devboard-Rev1-CuIn2.gbr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]
2026-03-27 Final Rev1 fix before ordering
    Fixed Y2 not having correct pinout
    Made pcb antenna smaller to have it closer to the edge of the board
    Final routing adjustments
    Adjusted RF matching circuit
    [BOM-SnapCore-Devboard-Rev1.csv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]
